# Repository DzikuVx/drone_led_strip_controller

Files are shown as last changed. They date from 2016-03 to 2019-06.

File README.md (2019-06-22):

# Dronsie Strip - LED strips controller for quadcopter drones

Although some flight controller software, like [Cleanflight](https://github.com/cleanflight/cleanflight) (and hardware) allows to attach WS2812B based RGB LED strips, it is far from perfect. For example, LED Strip support might disable SoftSerial or Sonar support depending on used hardware. And if you want add some bling to drone not running Cleanflight, you are on your own.

This is why, ***Dronsie Strip*** was created. It is small, independent, WS2812B LED strips controller designed to fit on 250 class quadcopters. 

Features:
* Size: 23x13mm
* Weight: less than 5g 
* 5V input, can be taken directly from BEC
* Supports 8 RGB LED strips based on WS2812B
* 1 button operated. Single button allows to change pattern and color. Short press changes patters, long press changes color

## BOM
* [ATtiny85](http://bit.ly/2XqkfwB) ~$1.5
* [Tactile button](http://bit.ly/2Kzawy3) ~$1.5 for 100pcs
* PCB depends on where you order it. Design is already on [OSHPark](https://oshpark.com/shared_projects/qaobZKzz)

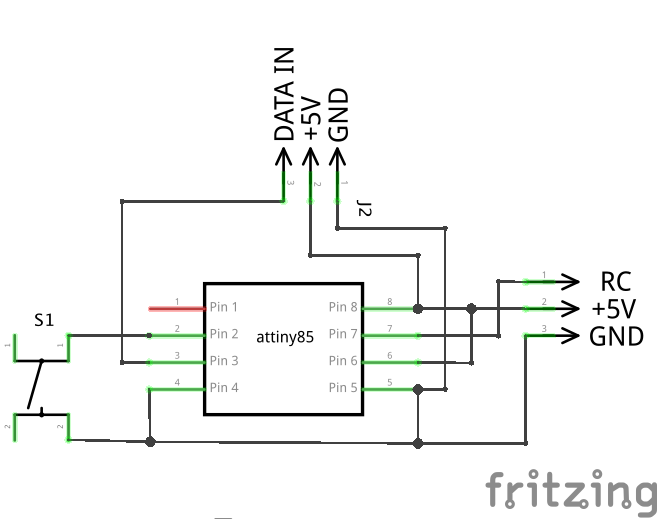
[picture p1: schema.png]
Diagram


How it works? One picture can be worth thousand words, so here is a small video

Dronsie Strip (http://www.youtube.com/watch?v=arccMxGvTm0 "Dronsie Strip")

# Notes
* Tested with [light_WS2812](https://github.com/cpldcpu/light_ws2812) 
* This code works with [ATtiny Classic](https://github.com/SpenceKonde/ATTinyCore) hardware definitions
* Tested with 8MHz internal oscillator

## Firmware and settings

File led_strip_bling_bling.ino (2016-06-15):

#include <avr/sleep.h>
#include <WS2812.h>
#include <EEPROM.h>
#include <PinChangeInterrupt.h>

#define adc_disable() (ADCSRA &= ~(1<<ADEN)) // disable ADC (before power-off)
#define adc_enable()  (ADCSRA |=  (1<<ADEN)) // re-enable ADC

#define RC_PIN 2
#define LED_NUMBER 8
#define LED_MULTIPLIER 4
#define LED_PIN 4
#define SLEEP_TIME 30
#define BUTTON_PIN 3
#define COLORS 7
#define LONG_PUSH_THRESHOLD 20
#define MAX_CYCLE 256
#define MODES 9
#define EEPROM_MODE_ADDRESS 0
#define EEPROM_COLOR_ADDRESS 1
#define LPF_FACTOR 0.8

const byte colors[COLORS][3] = {
    {255, 0, 0},
    {0, 255, 0},
    {0, 0, 255},
    {255, 0, 255},
    {255, 255, 0},
    {0, 255, 255},
    {255, 255, 255}
  };

WS2812 LED(LED_NUMBER * LED_MULTIPLIER);

byte mode = 0;
byte pushStartCycle;
byte i;
byte colorIndex = 0;
byte cycle = 0;

cRGB currentColor;
cRGB off;
cRGB background;

cRGB output[LED_NUMBER] = {};

volatile unsigned long risingStart = 0;
volatile unsigned int channelLength = 0;

int smooth(int data, float filterVal, float smoothedVal){

  if (filterVal > 1){ // check to make sure params are within range
    filterVal = .99;
  }
  else if (filterVal <= 0){
    filterVal = 0;
  }

  smoothedVal = (data * (1 - filterVal)) + (smoothedVal  *  filterVal);

  return (int)smoothedVal;
}

void setColor() {
  currentColor.r = colors[colorIndex][0];
  currentColor.g = colors[colorIndex][1];
  currentColor.b = colors[colorIndex][2];

  background.r = colors[colorIndex][0] / 5;
  background.g = colors[colorIndex][1] / 5;
  background.b = colors[colorIndex][2] / 5;
}

void setup() {
  adc_disable();
  LED.setOutput(LED_PIN);
  pinMode(BUTTON_PIN, INPUT_PULLUP);
  off.r = 0;
  off.g = 0;
  off.b = 0;

  mode = EEPROM.read(EEPROM_MODE_ADDRESS);
  if (mode >= MODES) {
    mode = 0;  
  }

  colorIndex = EEPROM.read(EEPROM_COLOR_ADDRESS);
  if (colorIndex >= COLORS) {
    colorIndex = 0;  
  }

  setColor();

  attachPinChangeInterrupt(RC_PIN, onChange, CHANGE);
}

void onChange(void) {
  uint8_t trigger = getPinChangeInterruptTrigger(RC_PIN);

  if(trigger == RISING) {
    risingStart = micros();
  } else if(trigger == FALLING) {
    unsigned int val = micros() - risingStart;
    channelLength = smooth(val, LPF_FACTOR, channelLength);
  }
}

void modeOff(byte currentCycle) {
  for (i = 0; i < LED_NUMBER; i++) {
    output[i] = off;
  }
}

void modeOn(byte currentCycle) {
  
  for (i = 0; i < LED_NUMBER; i++) {
    output[i] = currentColor;
  }
}

byte getDivider(byte denom, byte cycle) {
  return cycle / denom;
}

void modeSingleWander(byte currentCycle) {

  currentCycle = getDivider(2, currentCycle);

  for (i = 0; i < LED_NUMBER; i++) {
    output[i] = background; 
  }

  output[currentCycle % LED_NUMBER] = currentColor; 
}

void setOutput(byte led, cRGB color) {

//  if (led <= LED_NUMBER) {
    output[led] = color; 
//  }
  
}

void modeRapid(byte currentCycle) {

  for (i = 0; i < LED_NUMBER; i++) {
    output[i] = background; 
  }

  if (currentCycle == LED_NUMBER << 2) {
    cycle = 0;
    currentCycle = 0;
  }

  if (currentCycle < LED_NUMBER) {
    setOutput(currentCycle % LED_NUMBER, currentColor);

    if (currentCycle + 1 < LED_NUMBER) {
      setOutput((currentCycle + 1) % LED_NUMBER, currentColor);
    }
    if (currentCycle + 2 < LED_NUMBER) {
      setOutput((currentCycle + 2) % LED_NUMBER, currentColor);
    }
  } 
  
}

void modeBoldWander(byte currentCycle) {

  currentCycle = getDivider(2, currentCycle);

  for (i = 0; i < LED_NUMBER; i++) {
    output[i] = background; 
  }

  output[currentCycle % LED_NUMBER] = currentColor;
  output[(currentCycle + 1) % LED_NUMBER] = currentColor; 
}

void modeBolderWander(byte currentCycle) {

  currentCycle = getDivider(2, currentCycle);

  for (i = 0; i < LED_NUMBER; i++) {
    output[i] = off; 
  }

  output[currentCycle % LED_NUMBER] = currentColor;
  output[(currentCycle + 1) % LED_NUMBER] = currentColor; 
  output[(currentCycle + 2) % LED_NUMBER] = currentColor; 
  output[(currentCycle + 3) % LED_NUMBER] = currentColor; 
}

void modeDoubleWander(byte currentCycle) {

  currentCycle = getDivider(2, currentCycle);

  for (i = 0; i < LED_NUMBER; i++) {
    output[i] = off; 
  }

  output[currentCycle % LED_NUMBER] = currentColor; 
  output[(MAX_CYCLE - currentCycle) % LED_NUMBER] = currentColor; 

}

void modeChase(byte currentCycle) {

  currentCycle = getDivider(2, currentCycle);

  for (i = 0; i < LED_NUMBER; i++) {
    output[i] = off; 
  }

  output[currentCycle % LED_NUMBER] = currentColor; 
  output[(currentCycle + (LED_NUMBER / 2)) % LED_NUMBER] = currentColor; 

}

void modeFlash(byte currentCycle) {

  currentCycle = getDivider(2, currentCycle);

  cRGB state = off;

  if (currentCycle % 16 == 12 or currentCycle % 16 == 15) {
     state = currentColor;
  }

  for (i = 0; i < LED_NUMBER; i++) {
    output[i] = state; 
  }

}

byte previousPin = LOW;

byte controllState = LOW;
byte previousState = LOW;

void loop() {

  byte pin = digitalRead(BUTTON_PIN);

  controllState = LOW;

  if (channelLength > 1750 && channelLength < 2200 || digitalRead(BUTTON_PIN) == LOW) {
    controllState = HIGH;
  }

  if (controllState == HIGH and previousState == LOW) {
    pushStartCycle = cycle;
  }
  
  if (controllState == LOW and previousState == HIGH) {

    if (abs(cycle - pushStartCycle) > LONG_PUSH_THRESHOLD) {
      /*
       * Cycle color procedure
       */
      colorIndex++;
  
      if (colorIndex == COLORS) {
        colorIndex = 0;
      }
      EEPROM.write(EEPROM_COLOR_ADDRESS, colorIndex);
      setColor();

      cycle = 0;
      pushStartCycle = 0;
      
    } else if (abs(cycle - pushStartCycle) > 1) {
      mode++;

      if (mode == MODES) {
        mode = 0;
      }

      cycle = 0;
      pushStartCycle = 0;
      
      EEPROM.write(EEPROM_MODE_ADDRESS, mode);
    }
  }

  previousState = controllState;

  switch (mode) {

    case 0:
      modeOff(cycle);
      break;

    case 1:
      modeOn(cycle);
      break;

    case 2:
      modeSingleWander(cycle);
      break;

    case 3:
      modeBoldWander(cycle);
      break;
      
    case 4:
      modeDoubleWander(cycle);
      break;

    case 5:
      modeChase(cycle);
      break;

    case 6:
      modeFlash(cycle);
      break;

    case 7:
      modeBolderWander(cycle);
      break;

    case 8:
      modeRapid(cycle);
      break;
    
  }

  for (byte strip = 0; strip < LED_MULTIPLIER; strip++) {
    for (byte i = 0; i < LED_NUMBER; i++) {
      LED.set_crgb_at(i + (strip * LED_NUMBER), output[i]); 
    }
  }

  LED.sync();

  cycle++;
  if (cycle == MAX_CYCLE) {
    cycle = 0;
  }
  delay(SLEEP_TIME);
}

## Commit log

2016-02-03 PCB design and new blinking mode
    [led_strip_bling_bling.fzz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]
2016-02-17 code to match PCB design
2016-02-25 basic support of steering via RC RWM channel
2016-03-15 RC switch and multiple strips
2016-03-15 updated schema
    [led_strip_bling_bling.fzz]
2016-04-21 new pcb export
    [led_strip_bling_bling.fzz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]
